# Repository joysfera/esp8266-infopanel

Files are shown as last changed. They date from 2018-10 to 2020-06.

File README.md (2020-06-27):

# esp8266-infopanel
WiFi LED information panel built on ESP8266

Using either WS2812 kind of LED strip or MAX7219 based LED matrix modules.

Video presentation in Czech language here: https://youtu.be/nCY0f-b_-vU

Updated exactly a year later for OpenAlt 2019 - added complete application
"clock" using NodeMCU modules u8g2d, sntp, rtctime and enduser_setup.

MicroUSB connector that fits to the PCB is BI0001715, found e.g. here https://www.aliexpress.com/i/32763236347.html

petr@pstehlik.cz

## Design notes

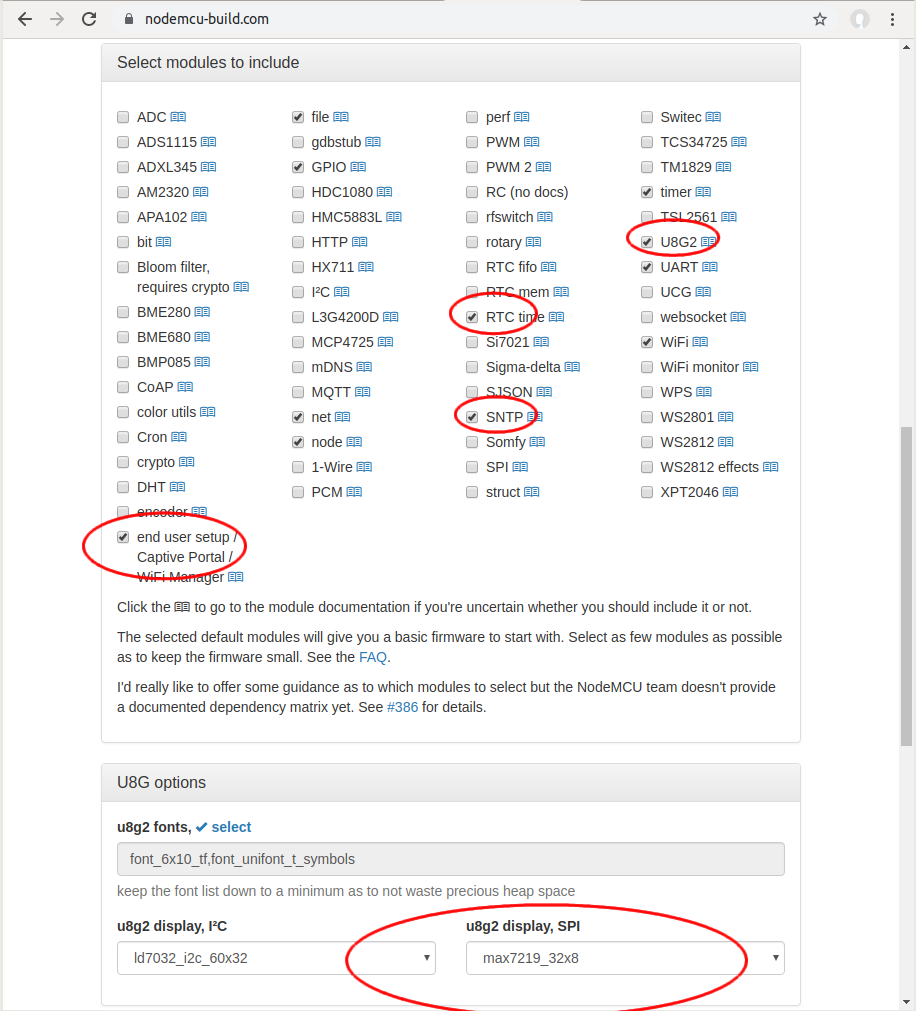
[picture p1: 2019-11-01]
SW/NodeMCU/clock/NodeMCU_modules.png

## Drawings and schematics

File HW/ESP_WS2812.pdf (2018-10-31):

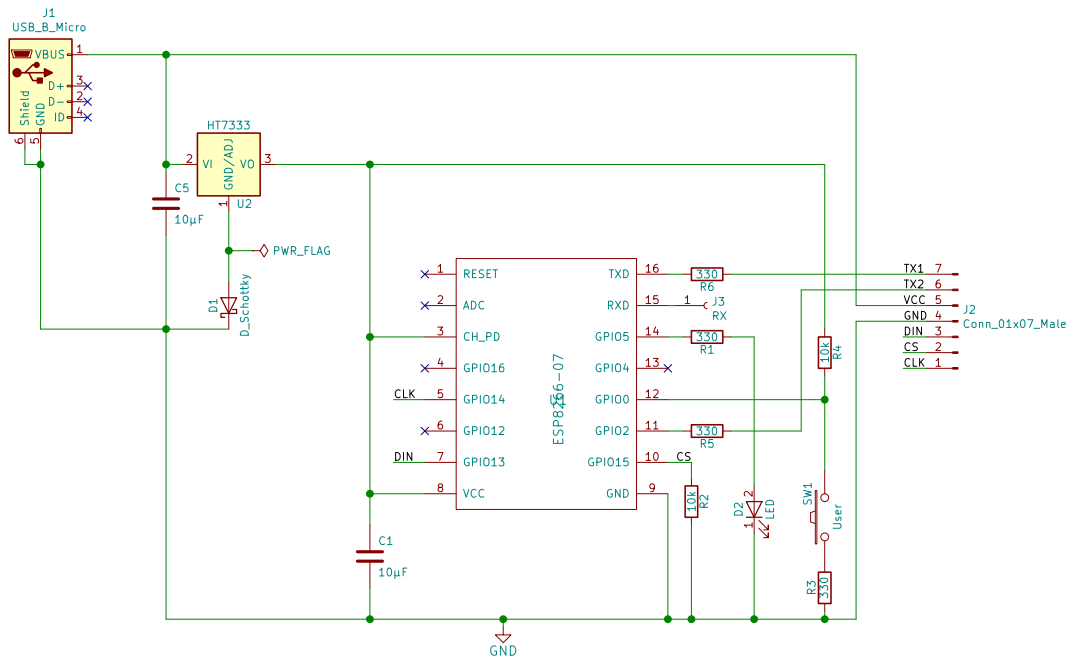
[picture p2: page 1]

File: ESP_WS2812.sch Sheet: / www.pstehlik.cz

Id: 1/1 Title: WiFi LED information panel

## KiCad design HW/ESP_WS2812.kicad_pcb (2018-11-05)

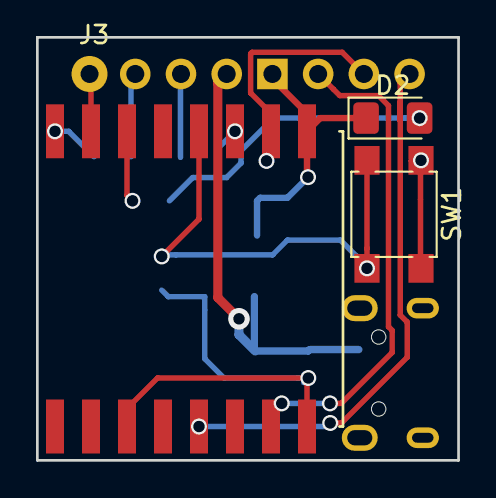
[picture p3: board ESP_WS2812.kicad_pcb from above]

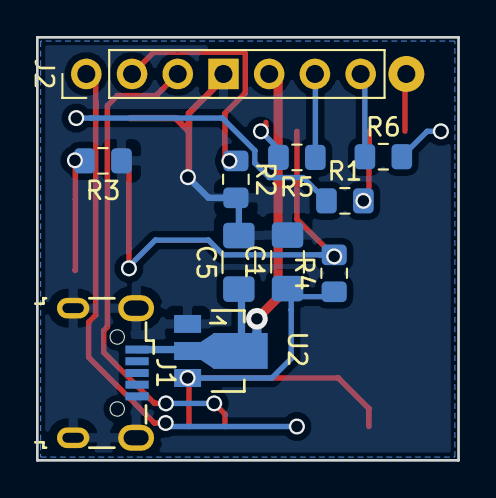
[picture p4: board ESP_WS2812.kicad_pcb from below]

Board: 2 copper layers, 23.4 x 23.5 mm, 15 parts (11 on the bottom side), 15 nets.

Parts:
C1, C5: 10µF; C_1206_3216Metric_Pad1.42x1.75mm_HandSolder
D2: LED; D_1206_3216Metric_Pad1.42x1.75mm_HandSolder
J1: USB_B_Micro; USB_Micro-B_Wuerth_629105150521
J2: Display; PinHeader_1x07_P2.54mm_Vertical
J3: RX; SolderWirePad_1x01_Drill0.8mm
R1, R3, R5, R6: 330; R_0805_2012Metric_Pad1.15x1.40mm_HandSolder
R2, R4: 10k; R_0805_2012Metric_Pad1.15x1.40mm_HandSolder
SW1: User; SW_SPST_TL3305A
U1: ESP8266-07; ESP-8266-07
U2: HT7335; SOT89-3_Housing

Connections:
/CLK: J2.1, U1.5
/CS: J2.2, R2.1, U1.10
/DIN: J2.3, U1.7
/TX1: J2.7, R6.1
/TX2: J2.6, R5.1
/VCC: C5.1, J1.1, J2.5, U2.2
GND: C1.2, C5.2, D2.1, J1.5, J1.6, J2.4, R2.2, R3.1, U1.9, U2.1
unnamed: C1.1, R4.1, U1.3, U1.8, U2.3
unnamed: D2.2, R1.1
unnamed: J3.1, U1.15
unnamed: R1.2, U1.14
unnamed: R3.2, SW1.1
unnamed: R4.2, SW1.2, U1.12
unnamed: R5.2, U1.11
unnamed: R6.2, U1.16

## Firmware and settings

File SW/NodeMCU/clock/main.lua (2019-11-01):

-- simple clock on MAX7219 based 32x8 LED matrix
-- driven by ESP8266 running NodeMCU with u8g2 library
-- Petr Stehlik @ https://github.com/joysfera

local function init_display()
    spi.setup(1, spi.MASTER, spi.CPOL_LOW, spi.CPHA_LOW, 8, 8)
    return u8g2.max7219_32x8(1, 8, 4) -- CS on GPIO 15
end

local function prepare_font()
    disp:setFont(u8g2.font_6x10_tf)
    disp:setFontRefHeightExtendedText()
    disp:setDrawColor(1)
    disp:setFontPosTop()
    disp:setFontDirection(0)
end

local function show_hello()
    disp:clearBuffer()
    disp:drawStr(0, 0, "Ahoj")
    disp:sendBuffer()
end

local function show_time()
    local tz_offset = 3600
    local tm = rtctime.epoch2cal(rtctime.get() + tz_offset)
    -- local tim = string.format("%02d:%02d", tm["hour"], tm["min"])
    local tim = string.format("%02d:%02d", tm["min"], tm["sec"])
    disp:clearBuffer()
    disp:drawStr(0, 0, tim)
    disp:sendBuffer()
end

disp = init_display()
prepare_font()
show_hello()

enduser_setup.start(
    function()
        sntp.sync(nil, nil, nil, 1)
        tmr.create():alarm(1000, tmr.ALARM_AUTO, show_time)
    end,
    function(err, str)
        print("enduser_setup: Err #" .. err .. ": " .. str)
    end,
    print -- Lua print function can serve as the debug callback
)

--[[
// vim: tabstop=4 shiftwidth=4 expandtab cindent
--]]

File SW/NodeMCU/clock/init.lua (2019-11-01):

local abort = false

local function abortTest(data)
    abort = true    -- user requested abort
    uart.on('data') -- turns off uart scanning
end

local function abortInit()
    print('Press ENTER to abort startup')
    -- if <CR> is pressed, call abortTest
    uart.on('data', '\r', abortTest, 0)
    -- start timer to execute startup function in 1 second
    tmr.create():alarm(1000, tmr.ALARM_SINGLE, function()
        if abort then return end  -- if user requested abort, exit
        abort = nil
        uart.on('data')
        dofile('main.lc')
    end)
end

tmr.create():alarm(200, tmr.ALARM_SINGLE, abortInit) -- call abortInit after 0.2s

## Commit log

2018-10-31 schematics and PCB exported from KiCad
2018-11-05 KiCad files, revision 2 (Schottky diode removed, HT7335 used instead)
    [ESP_WS2812.kicad_pcb, ESP_WS2812.sch]
2019-11-01 added complete application displaying current time thanks to SNTP
2020-06-27 microUSB connector type documented
